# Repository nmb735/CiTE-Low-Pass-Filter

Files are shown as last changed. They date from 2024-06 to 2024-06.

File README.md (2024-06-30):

# 🎚️ CiTE: Fourth Order Low Pass Filter

Full implementation of a fourth-order low-pass filter. The circuit design is based on the use of two cascaded second-order Sallen-Key configurations. Presented as the final project for CiTE (*Circuits i Tecnologies Electròniques*), part of the third course of the Electronic Engineering degree (BSc).

## 👨‍💻 Developers

- Adrià Arús - @Addruss
- Nedal Benelmekki - @nmb735
- Marc Serra - @Marcits

## 📋 Context and Introduction

- This project involves the full implementation of a fourth-order low-pass filter. The circuit design is based on the use of two cascaded second-order Sallen-Key configurations. It was presented as the final project for CiTE (*Circuits i Tecnologies Electròniques*), part of the third course of the Electronic Engineering degree (BSc).

- The project encompassed the entire process, including circuit and PCB design, manufacturing, soldering, and testing.

## 📂 Content

This repository contains the full project in different directories:

1. **`EAGLE Project`**: Full PCB project (`EAGLE` software, from Autodesk), including Layout, Schematic, Gerber Files, BOM, and other related files.
2. **`Documentation`**: Project documentation and presentation poster.

## 📝 License

This project is licensed under the MIT License. See the LICENSE file for more details.

## ⚠️ Disclaimer

This project is provided for educational purposes only. The authors are not responsible for any use of this project in any form of academic dishonesty or plagiarism. Please adhere to your institution's academic integrity policies when using or referencing this project.

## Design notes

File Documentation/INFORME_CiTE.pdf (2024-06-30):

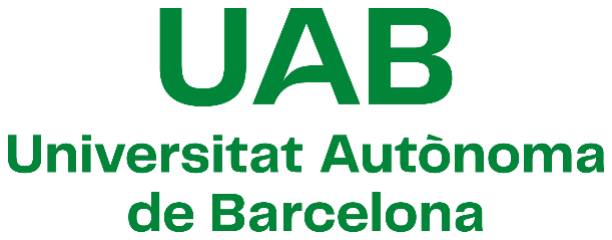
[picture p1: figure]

# DISSENY I FABRICACIÓ D’UN FILTRE EN PCB

ADRIÀ ARÚS SETÓ - 1632367
NEDAL MARTÍNEZ BENELMEKKI - 1632368 MARC SERRA ASENSIO - 1632823

Adrià Arús Setó | Nedal Martínez Benelmekki | Marc Serra Asensio
DISSENY I FABRICACIÓ D’UN FILTRE EN PCB

## Contingut

## Objectiu

Durant les pràctiques, s’havia de dissenyar un filtre passa-baixos (aproximació Butterworth) d’ordre quatre, implementat amb dues configuracions Sallen-Key de segon ordre en cascada.

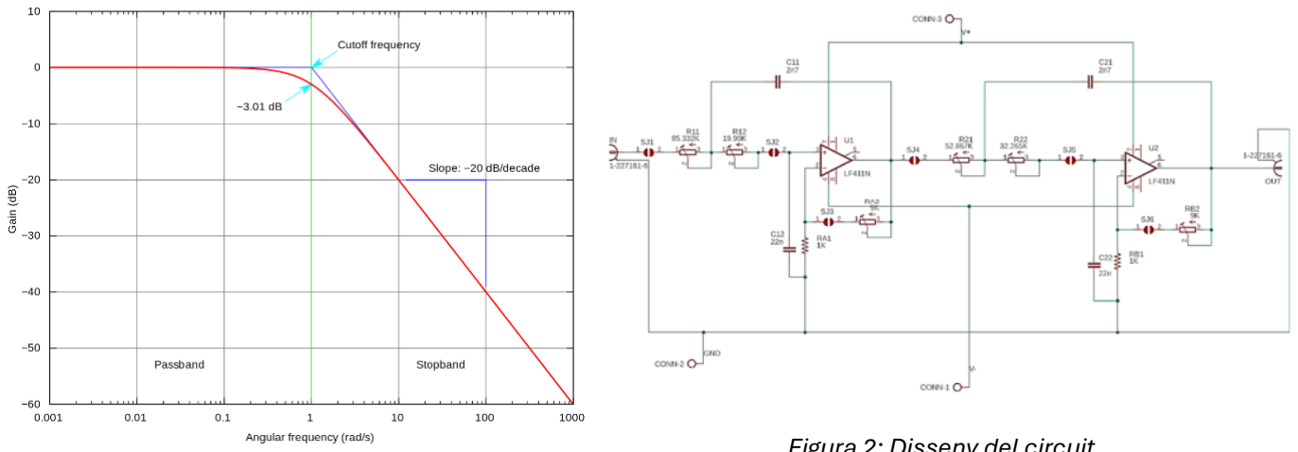
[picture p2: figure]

El filtre tindrà una banda de pas amb un guany de 40 dB (100 en lineal) amb una freqüència de tall de 500 Hz (freqüència on el guany cau 3 dB).

A la primera sessió de pràctiques es va dissenyar el circuit que implementa el filtre, seleccionant els components adequats i amb els valors corresponents. A continuació, a la segona pràctica, es varen descobrir els processos de fabricació d'aquest tipus de plaques. Seguint a la tercera pràctica, on se soldaren els components a la placa, construint el filtre desitjat. Finalment, a la quarta pràctica, es va dur a terme el test del circuit final muntat a la PCB.

Figura 1: Filtre patró

Figura 2: Disseny del circuit.

## Disseny de la PCB

La primera etapa de tot el procés consistia en dissenyar la PCB. Per a aquesta fase de disseny, calia familiaritzar-se amb softwares de tipus ECAD (Electronic Computer Assisted Design). Tot i que hi ha moltes eines diferents, com ara Altium Designer (estàndard de la indústria), CircuitMaker, o KiCad (entre moltes altres), s’ha realitzat tot el procés de disseny mitjançant Eagle, una eina produïda per Autodesk, la prestigiosa empresa d’eines CAD.

En el cas concret de la pràctica, es requerien diverses etapes, o capes, per a realitzar el circuit. En primer lloc, s’havia de crear una llibreria per poder utilitzar un component que no existia en la llibreria per defecte d’Eagle. Un cop creada la llibreria, es requeria desenvolupar l’esquemàtic (schematic), el layout de la placa i els arxius de fabricació. Tanmateix, tot i que no es demanava, per continuar amb les millors pràctiques del disseny electrònic, també s’afegirà una llista de materials (Bill of Materials).

A continuació, es detalla cada un d’aquests subapartats.

### Desenvolupament d’una llibreria

Com bé s’ha esmentat anteriorment, el disseny del filtre proposat s’implementa amb un component que no existeix a les llibreries estàndard del programari Eagle. Així doncs, es procedeix a crear una llibreria pròpia amb un únic component: el potenciòmetre TSM4 de Vishay.

A l’hora de definir una llibreria, hi ha quatre camps que es poden emplenar: dispositius, footprints, paquets 3D i símbols. Com que no es visualitzarà el render de la placa en 3D (ja que això se surt de l’abast de la pràctica) i només s’hi afegeix un dispositiu, s’hauran d’emplenar tres camps. En primer lloc, es tracta el símbol. Des del punt de vista de component per a un esquemàtic, el TSM4 continuarà sent un potenciòmetre (amb tres terminals) i, per tant, es pot reutilitzar un símbol més general d’un potenciòmetre. Específicament, s’ha utilitzat el símbol corresponent a POT-EU.

Un cop definit el símbol, cal crear el seu footprint. El footprint del
component descriu com és físicament i té importància a l’hora de
dissenyar el layout de la PCB. Mitjançant el footprint es defineixen característiques fonamentals del component, com ara la naturalesa de la seva tecnologia (SMD – Surface Mount Device, o THD – Through Hole Device) i les seves dimensions. Al datasheet del component es troben les dimensions corresponents, i s’ha aconseguit implementar el footprint i el corresponent silkscreen (per poder localitzar correctament el component en la placa física). A continuació, s’adjunta una figura amb el resultat final.

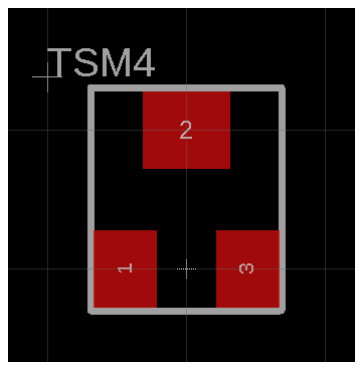
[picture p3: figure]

Figura 3: Implementació del footprint del TSM4

Un cop obtingut el footprint i el símbol del component, el següent i últim pas és el Device. El dispositiu (Device) és la integració del símbol amb el footprint per acabar de caracteritzar el component mitjançant la relació entre les connexions del símbol elèctric i les parts reals i/o físiques, i la petjada del component. Un cop finalitzat aquest procés, es pot desar la llibreria al directori on es troben les altres llibreries d’Eagle. D’aquesta manera, el component desitjat ja pot ser utilitzar en els dissenys a partir de la importació de la llibreria.

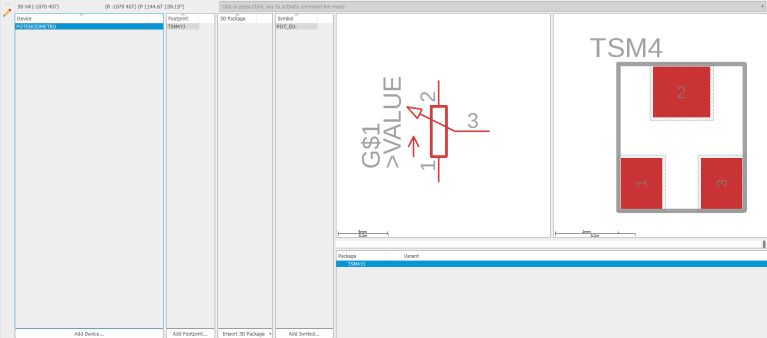
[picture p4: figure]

Figura 4: Llibreria finalitzada. Símbol, footprint i device acabats.

### Schematic (Esquemàtic)

La generació del schematic és una etapa relativament senzilla. Gràcies a la realització de la “Pràctica 0”, ja es disposa del disseny del filtre amb el circuit en format PDF, es proporciona la llista de components, i amb la implementació de la llibreria es té accés a tots els components. D’aquesta manera, només cal implementar el circuit, de manera molt similar a com es fa en simuladors SPICE.

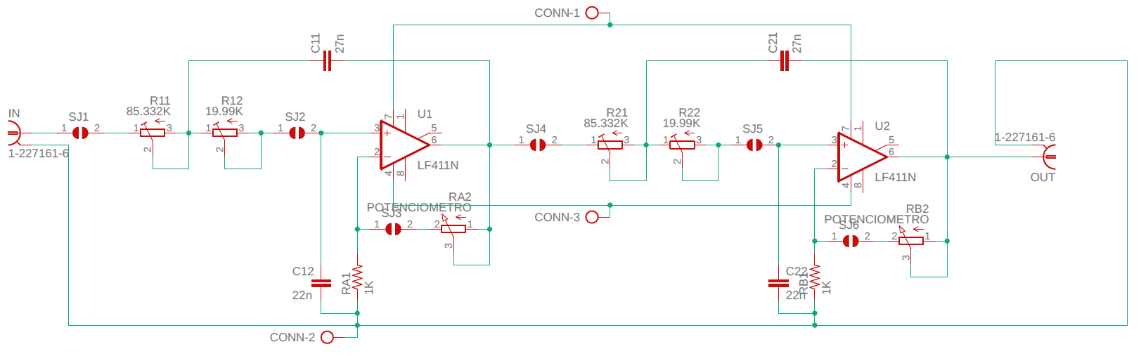
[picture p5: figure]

Figura 5: Schematic realitzat.
Cal recalcar, però, que generalment els schematics en eines de disseny de PCBs no es realitzen d’aquesta manera. En aquest cas particular, a causa de la simplicitat del circuit i la seva repetitivitat (dues configuracions Sallen-Key de segon ordre en cascada), a més de la familiaritat amb eines SPICE, es permet enfocar el disseny del schematic així. No obstant això, generalment en aquest apartat es troben els diversos mòduls de la PCB, ordenats segons la seva utilitat i no pel seu layout. En aquest cas, es podrien haver separat les dues configuracions Sallen-Key com a dos mòduls separats i indicar la seva connexió per nom (etiquetant el net), però es pot argumentar que això afegiria una capa de complexitat innecessària.

Finalment, es revisa que no hi hagi cap error amb l'Electrical Rule Check (ERC). A causa que components com l’amplificador operacional no s’alineen bé amb la resta, ha calgut solucionar alguns avisos de connexions que “estaven molt a prop, però no es tocaven”. S’han solucionat aquests avisos, però encara queden altres que no s’han pogut resoldre, com la falta de valors de components (marca tots els jumpers i I/O BNC com a warning) i les alimentacions de l’amplificador operacional. El més important, però, és que supera l’ERC sense cap errada. S’adjunta una imatge a continuació.

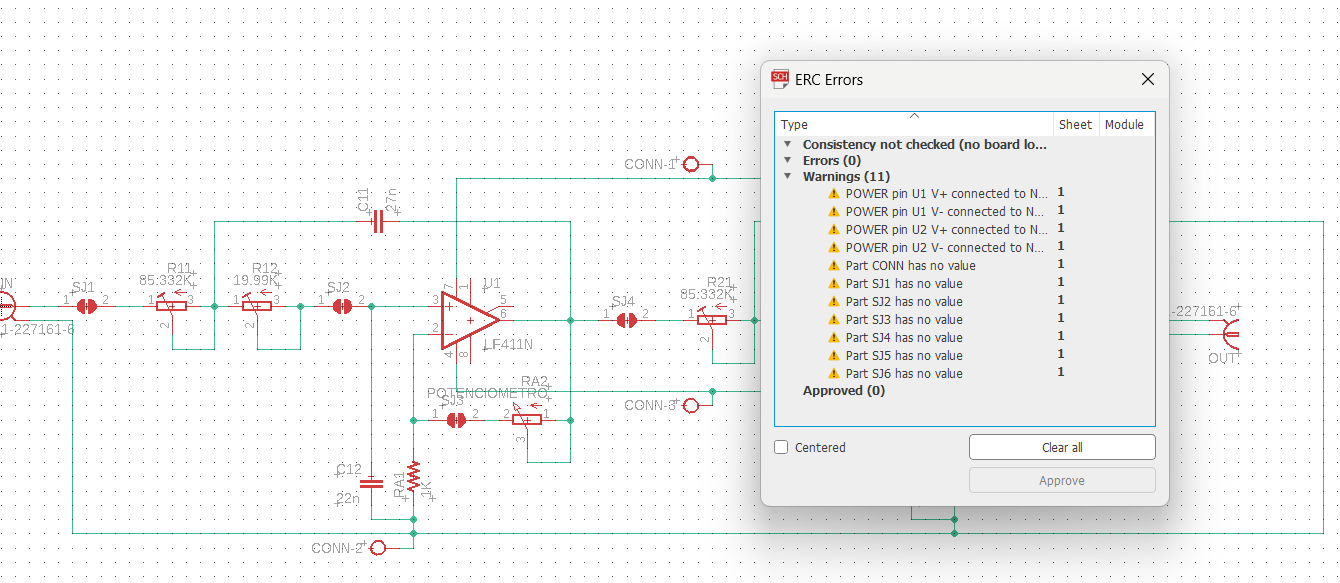
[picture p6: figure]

Figura 6: Schematic sense errades.

### Layout de la PCB

Un cop finalitzat el Schematic, es procedeix a realitzar el Layout. Per l’experiència obtinguda i per la documentació d’Eagle, és convenient mantenir obert tant l’esquemàtic com l’arxiu de layout, ja que d’aquesta manera se sincronitzen els canvis automàticament.

Inicialment, s’havia de definir la mida de la PCB. A la capa de Dimensions es defineix el polígon equivalent i s’adjunten les mesures. Posteriorment, es defineixen les regles DRC, es realitzen els forats de fixació, es col·loquen els components, es realitzen les vies (a la capa bottom) i s’afegeix el pla de massa (a la capa top). El resultat final és el següent:

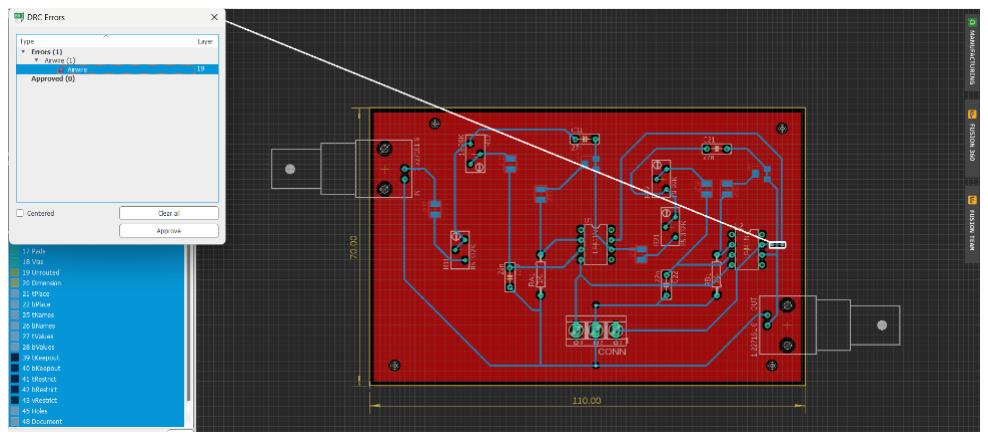
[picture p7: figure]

Figura 7: Resultat final de PCB.

Com bé es pot observar, hi ha una errada de circuit obert. Aquesta no es pot resoldre, ja que per la naturalesa del nostre circuit, és impossible trobar un camí del circuit que no causi un encreuament. De fet, si es modela el circuit com un graf, aquest no compliria el principi d’Euler, confirmant així la hipòtesi. A conseqüència s’afegeixen dues vies, per, de manera igual a la que es va fer experimentalment al laboratori, es pugui utilitzar un jumper wire (pont) per realitzar la connexió.

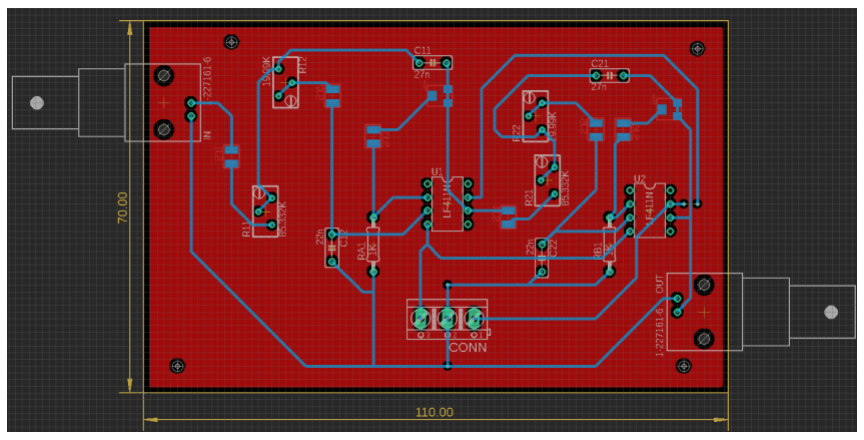
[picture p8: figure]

Figura 8: Layout de la PCB.
Així doncs, s’ha realitzat el layout de la PCB. Per comprovar que està tot correcte (temes de silkscreen, o forats, entre d’altres), s’utilitza l’eina “Manufacturing” d’Eagle, que permet veure un render en dues dimensions de la placa:

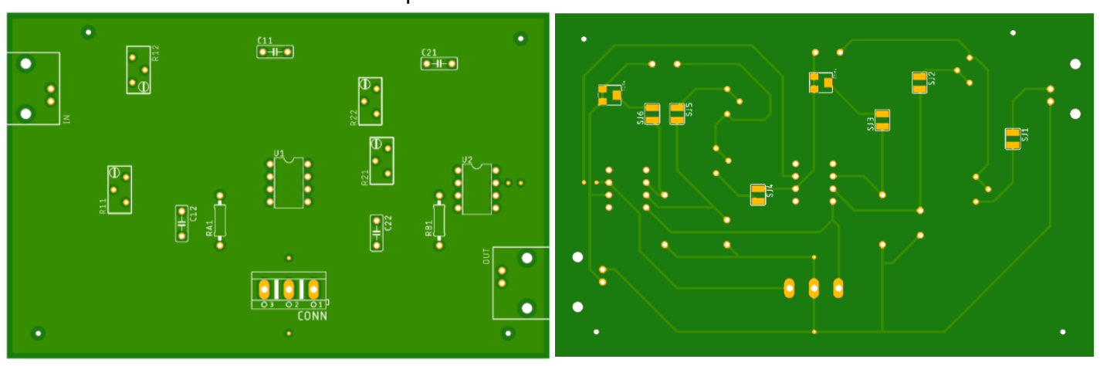
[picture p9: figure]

Figura 9: Render de la PCB en dues dimensions (Esquerra: capa top, Dreta: capa bottom)

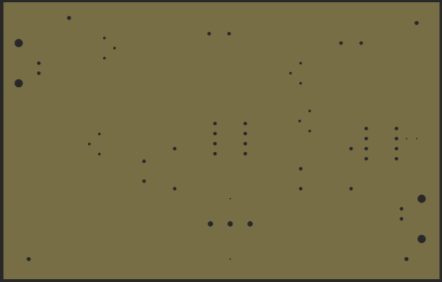
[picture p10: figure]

Figura 10: Render dels forats (drills) de la PCB.

### Arxius de fabricació i Bill of Materials

Des del Schematic, seleccionem “File”, després “Export” i finalment “BOM”. D’aquesta manera, es pot exportar un llistat del BOM (Bill of Materials). S’ha afegit aquest arxiu a la carpeta del projecte, en format CSV (BOM.csv).

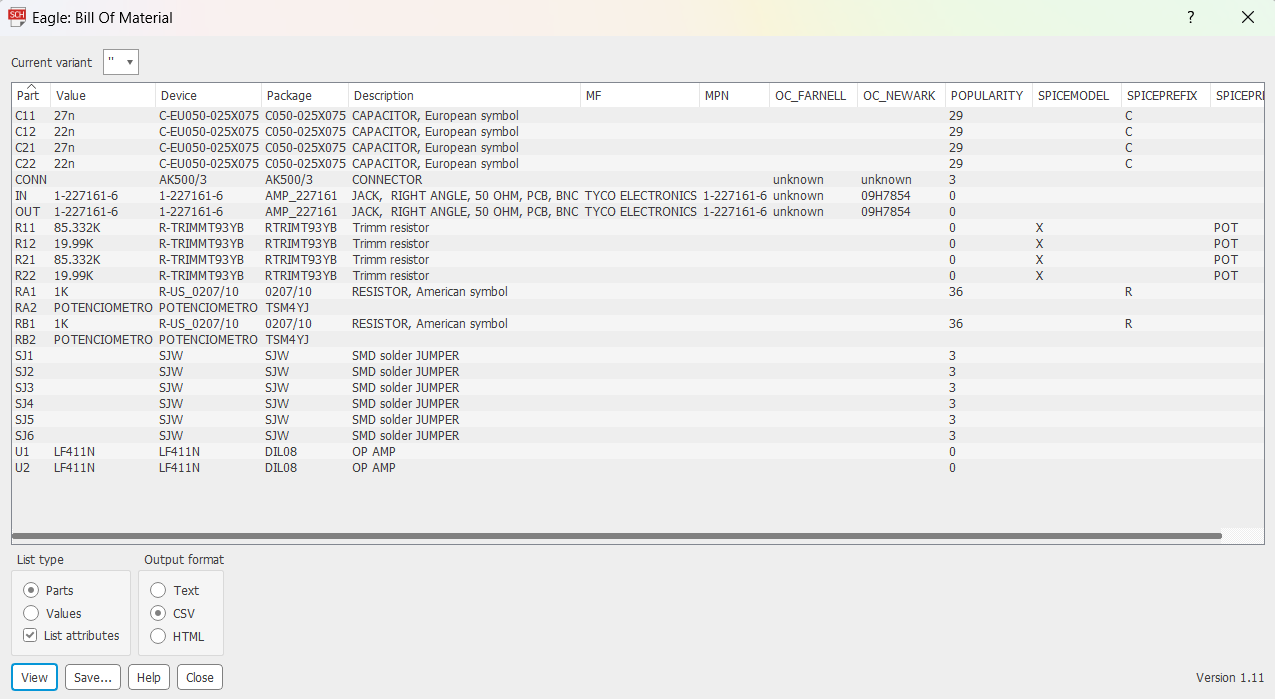
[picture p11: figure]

Figura 11: Generació del BOM.
Finalment, des de l’arxiu del layout, se selecciona l’opció de generar els fitxers Gerber (Generate CAM data). S’emmagatzemen aquests arxius en una carpeta ZIP al directori del projecte (Gerber_Files.zip).

## Fabricació de la placa

En una de les sessions de les pràctiques es van explicar tres processos de fabricació d’una placa PCB. Dos d’aquests processos eren de tipus subtractiu i l’altre de tipus additiu. Els processos subtractius consisteixen en el fet que el material conductor amb el que es fan les pistes es troben inicialment a la placa i es treu d’allà on no es vol. Per contra, els processos additius consisteixen a afegir el material conductor a un substrat que inicialment no el té.

Veiem ara en més detall cada un dels processos.

### Fotolitografia

Es tracta d'un dels dos processos subtractius i consisteix a remoure el coure a partir d'atacs químics en aquelles zones desprotegides d'una resina sensible a la llum. Els passos són els següents:
Primerament, es fa una rentada del coure tot per evitar impureses com l'òxid de coure a causa de l'exposició amb l'aire. Seguidament, es fa la sensibilització que consisteix a dipositar una resina fotosensible. Aquests dos primers passos no es van veure, ja que la placa PCB ja venia amb la resina fotosensible protegint la superfície del coure.
El procés continua amb la definició de la màscara a partir d'una impressora en un material transparent. En el cas de les pràctiques, les parts que tapava la màscara eren les pistes deixant al descobert la resina fotosensible allà on no volem coure. Idealment, els coeficients d'expansió tèrmica del material transparent és igual al de la placa. En cas contrari, es podria perdre definició.
Seguidament, s'exposa la resina fotosensible a llum ultraviolada (la més energètica per accelerar el procés) en una insoladora per debilitar les parts desprotegides de la màscara. Cal tenir en compte que hi ha casos on succeeix el contrari, és a dir, que és la part que no ha rebut llum ultraviolada la debilitada, però en les pràctiques es va veure el primer cas.
Després es fa un revelatge retirant la resina debilitada amb sosa càustica (molt
diluïda) exposant així el coure que es vol remoure de la placa. A continuació es fa l'atac químic en el qual es treu el coure amb clorur fèrric en aquelles parts on no hi ha resina.

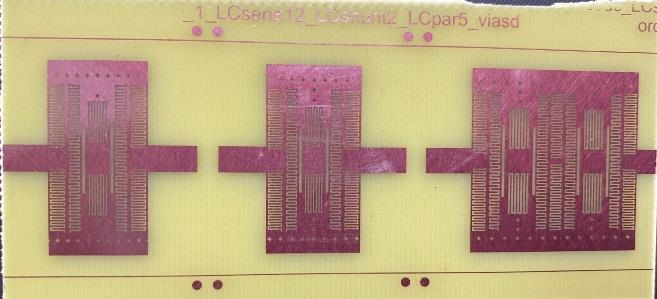
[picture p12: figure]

Figura 12: Exemple de fotolitografia després del revelatge
Finalment es fa un despreniment de la resina que en s’ha servit per protegir el coure de les pistes.

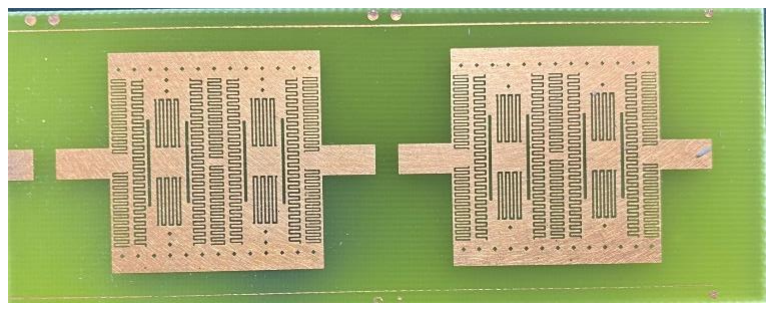
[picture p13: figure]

Figura 13: Resultat final

### Fresat

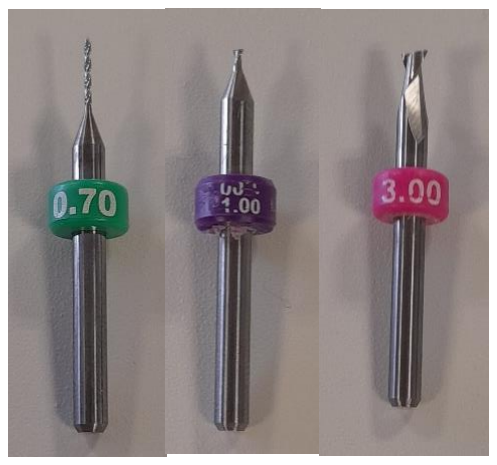
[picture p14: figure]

Aquesta és l’altra tècnica subtractiva. En aquest cas es remou el coure amb una màquina que té una peça giratòria anomenada fresa. El procediment que segueix la màquina consisteix en els passos descrits a continuació.

Primer la màquina s’alinea de manera automàtica i es fan els forats. Seguidament remou el coure amb les freses. Aquestes són de carbur tungstè i es van canviant de diàmetre segons la necessitat (poden anar des de 0.2 mm fins a 3 mm).

Finalment es talla per obtenir la peça.

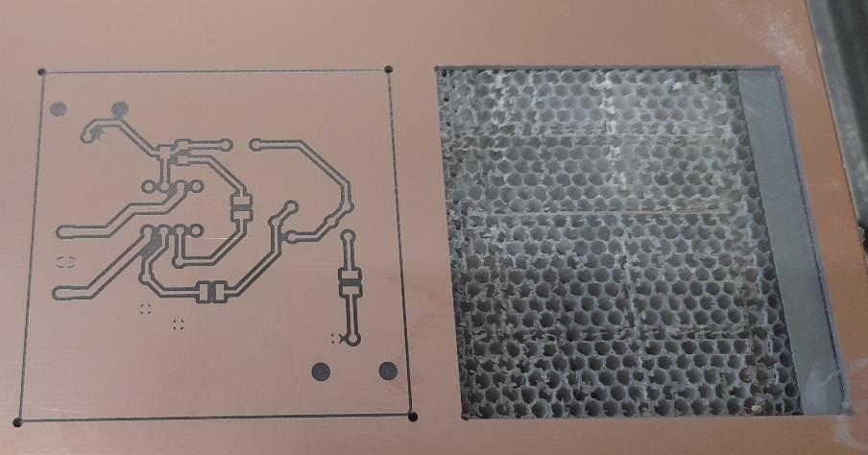
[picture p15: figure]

Figura 15: Lamina abans i després del tall
Aquest procediment té com a contrapartida que és notablement més car, ja que les freses són cares i es desgasten amb l’ús.

### Impressió amb tinta conductora

Aquesta darrera tècnica és l'additiva, també coneguda com a "injecció de tinta". Com bé indica el seu nom, es basa en una màquina (amb un cost d'aproximadament 5.000 €) que imprimeix les

Figura 14: Freses de diferents mides pistes directament sobre la placa mitjançant uns cartutxos de tinta, que costen uns 100 € cadascun.

El procés d'ús és força senzill en comparació amb les dues tècniques anteriors. La màquina esmentada, mitjançant un èmbol i l'aplicació de pressió sobre aquest, dissipa un material (generalment plata o algun altre material amb partícules de plata). Aquesta impressió es pot realitzar des d'una plantilla o a mà alçada, amb la placa en blanc. Així, indicant al programari associat a la màquina quin tipus de tinta es té, i seguint les instruccions proporcionades (és un procés molt guiat), es pot començar a imprimir el circuit. Cal tenir en compte que la placa sobre la qual s'imprimeix ha de ser plana i uniforme.

Un cop realitzada tota aquesta fase de preparació, es pot procedir a la impressió del circuit. Inicialment, s'ha de muntar la punta de calibració, on es calibrarà l'alçada, es farà una calibració en moviment, i es marcaran els límits del circuit. Un cop calibrat, es començarà a pintar amb un patró de "tocs" per acabar la calibració. La finalització d'aquests "tocs" marca la fi del procés de calibració. El programari ho indicarà i donarà la instrucció de començar la impressió.

Girant l'èmbol s'aconsegueix afegir pressió fins que surti la tinta. Quan això succeeix, netegem la punta i la col·loquem a la màquina. La màquina imprimirà unes línies de calibració. Si està tot correcte, es continua seguint les instruccions del programari. Si no, es pot esborrar amb alcohol i paper, ja que el material encara no s'ha solidificat.

Finalment, es procedeix a imprimir el circuit. Cal
anar amb compte perquè s'han de curar les pistes
per acabar de solidificar-les. Amb el circuit resultant, es poden soldar components manualment, tenint en compte les limitacions de material i temperatura. No obstant això, també existeix l'opció de soldar amb la mateixa màquina, canviant el material de la tinta.

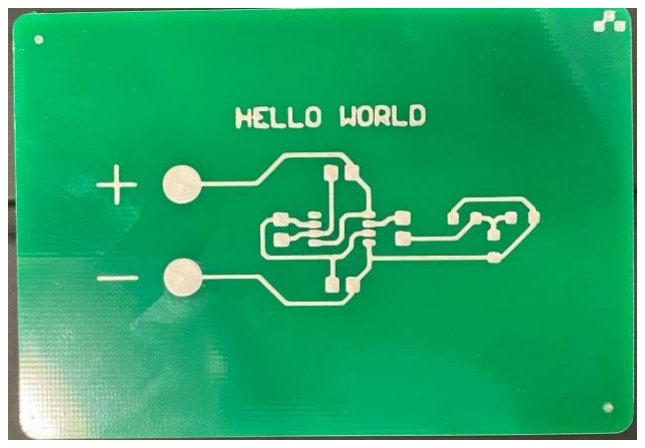
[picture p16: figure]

Figura 16: Resultat de la tècnica additiva

## Muntatge dels components

En el cas de les pràctiques, es van fer soldadures a mà dels diferents components sobre la placa PCB. A més dels components necessaris, es van utilitzar un soldador amb una esponja mullada, estany i una malla metàl·lica.

Abans de començar, calia escalfar el soldador a la temperatura correcta, la qual cosa es comprovava amb una mica d’estany. El procés de soldar consistia a escalfar el metall de la placa i del component, i un cop calent, afegir l’estany perquè la soldadura quedés ben mullada i sense excessos de material.

Aquest grup va tenir problemes inicials per entendre bé el funcionament, però finalment es van realitzar totes les soldadures satisfactòriament. Es va demanar feedback al professorat, i es van rebre comentaris positius quant a la qualitat de les soldadures. A continuació es mostren fotografies dels resultats.

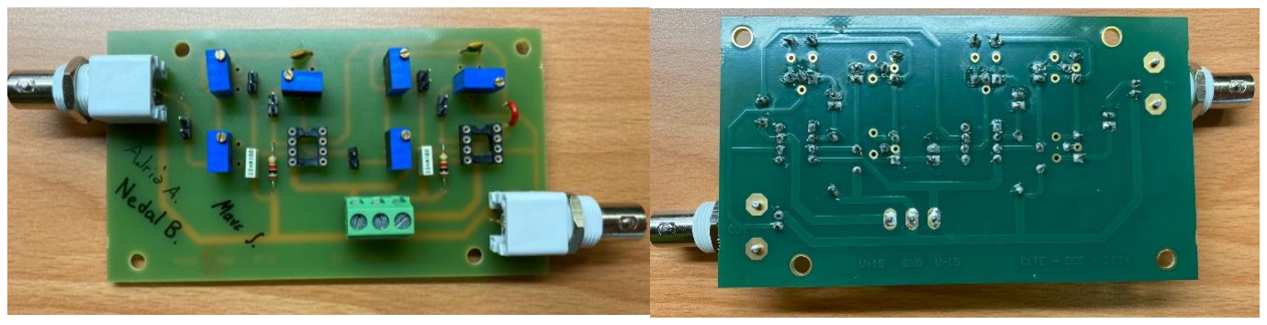
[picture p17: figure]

Figura 17: Resultats del muntatge.

## Test del circuit

Una vegada implementada la placa, s’han calibrat els components amb els valors nominals. Per testejar el funcionament del filtre, es fa un escombrat de freqüències veient el resultat. S’ha generat un diagrama de Bode per a poder comprovar que el nostre sistema funciona correctament:

f [Hz] | Vin [V] | Vout [V] | G | G [dB] | Atenuació [dB]
1,00E+00 | 1,00E-01 | 1,24E+01 | 124 | 41,8684337 | 0
1,00E+01 | 1,00E-01 | 1,24E+01 | 124 | 41,8684337 | 0
1,00E+02 | 1,00E-01 | 1,24E+01 | 124 | 41,8684337 | 0
1,25E+02 | 1,00E-01 | 1,17E+01 | 1,17E+02 | 41,34885686 | 0,519576848
1,50E+02 | 1,00E-01 | 1,09E+01 | 1,09E+02 | 40,73257791 | 1,135855796
1,75E+02 | 1,00E-01 | 9,76E+00 | 9,76E+01 | 39,78899635 | 2,07943735
2,00E+02 | 1,00E-01 | 8,68E+00 | 8,68E+01 | 38,7703945 | 3,0980392
2,25E+02 | 1,00E-01 | 7,60E+00 | 7,60E+01 | 37,61627185 | 4,252161858
2,50E+02 | 1,00E-01 | 6,60E+00 | 6,60E+01 | 36,39087871 | 5,477554992
2,75E+02 | 1,00E-01 | 5,68E+00 | 5,68E+01 | 35,08696671 | 6,781466989
3,00E+02 | 1,00E-01 | 4,88E+00 | 48,8 | 33,76839644 | 8,100037263
3,50E+02 | 1,00E-01 | 3,48E+00 | 3,48E+01 | 30,83158488 | 11,03684882
4,00E+02 | 1,00E-01 | 2,48E+00 | 2,48E+01 | 27,88903362 | 13,97940009
4,50E+02 | 1,00E-01 | 1,80E+00 | 1,80E+01 | 25,1054501 | 16,7629836
5,00E+02 | 1,00E-01 | 1,28E+00 | 1,28E+01 | 22,14419939 | 19,72423431
5,50E+02 | 1,00E-01 | 9,38E-01 | 9,38 | 19,44405677 | 22,42437694
6,00E+02 | 1,00E-01 | 7,14E-01 | 7,14 | 17,07396424 | 24,79446947
7,00E+02 | 1,00E-01 | 4,24E-01 | 4,24 | 12,54731713 | 29,32111657
8,00E+02 | 1,00E-01 | 2,60E-01 | 2,6 | 8,299466959 | 33,56896674
9,00E+02 | 1,00E-01 | 2,00E-01 | 2 | 6,020599913 | 35,84783379
1,00E+03 | 1,00E-01 | 1,82E-01 | 1,82 | 5,20142776 | 36,66700594
2,00E+03 | 1,00E-01 | 1,40E-01 | 1,4 | 2,922560714 | 38,94587299
5,00E+03 | 1,00E-01 | 9,60E-02 | 9,60E-01 | -0,354575339 | 42,22300904

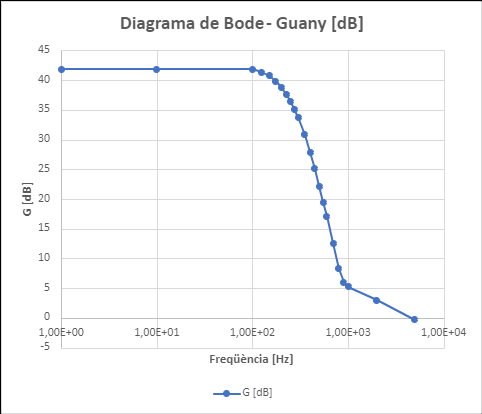
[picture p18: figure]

Figura 18: Diagrama de Bode utilitzant els valors nominals.

S'observa la forma d'un filtre Butterworth passa-baixos, amb un guany d'uns 41 dB (124 en lineal) a la banda de pas i una freqüència de tall de al voltant de 200 Hz. A la banda atenuant es veu un pendent d'uns 80 dB per dècada, conseqüència de l'ordre 4 del filtre.
Es pot comparar el resultat d'amplificar un senyal en la banda de pas (100 Hz) amb el de la banda atenuant (400 Hz) per a una entrada d'amplitud 50 mV:

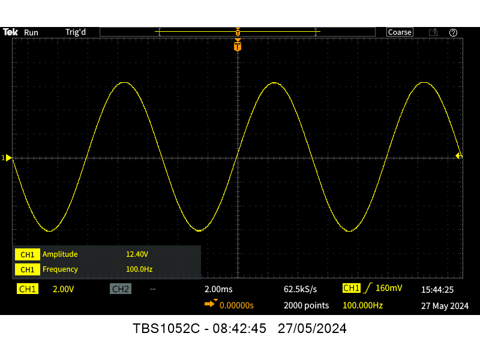
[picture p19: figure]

Figura 19: Guany a la banda passant.

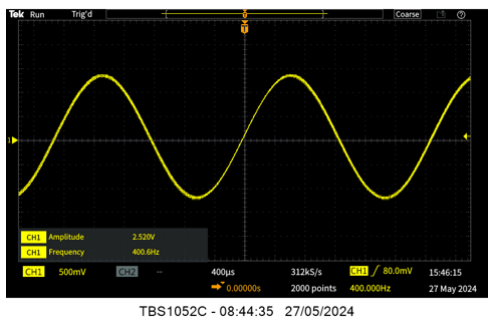
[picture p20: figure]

Figura 20: Guany/Atenuació a la banda d'atenuació.

Ajustant els valors als del disseny s’obté el següent diagrama de Bode:

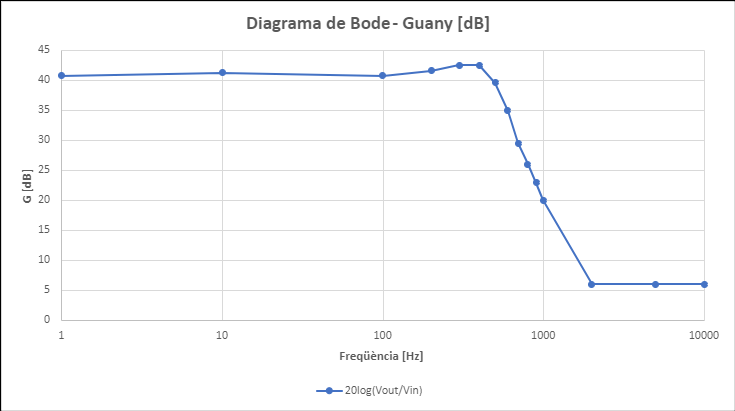
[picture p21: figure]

Figura 21: Diagrama de Bode amb els valors ajustats.

Com es pot observar, a causa de no idealitats tenim un factor de qualitat més elevat del desitjat.

En conclusió, el nostre sistema implementa un filtre Butterworth passa-baix totalment funcional.

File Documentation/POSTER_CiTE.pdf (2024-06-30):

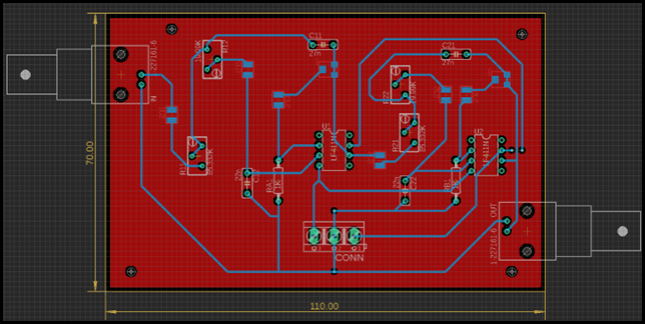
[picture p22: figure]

Adrià Arús Setó (1632367)

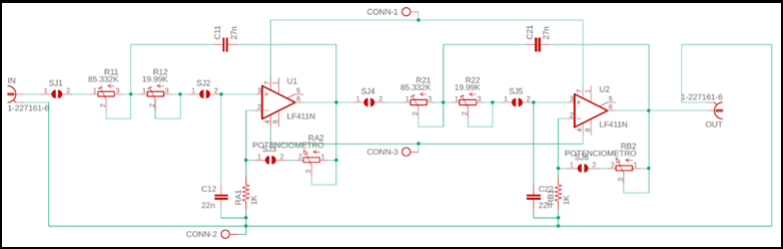
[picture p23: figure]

Nedal Martínez Benelmekki (1632368) Marc Serra Asensio (1632823)

### Autors

Universitat Autònoma de Barcelona (UAB) Circuits i Tecnologies Electróniques

El disseny de la PCB s

’ha realitzat mitjançant el programari Eagle. S’han realitzat les següents etapes:

Desenvolupament d’una llibreria En el disseny proposat, existia un component no present en les llibreries d’Eagle. Consequentment, s

’ha implementat una llibreria (símbol, footprint, i device) per poder utilitzar el component (TSM4 de Vishay).

Schematic (Esquemàtic)
Realització d’

un dels arxius més importants d’

un projecte de disseny de PCB. S’ha comprovat que no hi ha cap errada ERC (Electrical Rule Check).

Layout de la PCB
Realització del layout de la placa, tenint en compte les dimensions físiques (de components i placa) i les regles de disseny.

Arxius de fabricació i Bill of Materials Generació dels arxius de fabricació (Gerber files) a partir del layout (emmagatzemats en un ZIP), i generació del BOM (Bill of Materials) a partir del schematic. Mitjançant aquests dos, es pot iniciar la etapa de producció i muntatge.

Implementació del footprint

Schematic del circuit

Layout de la PCB i renders en dues dimensions de la capa top (centre) i la capa bottom (esquerra).

Resultats del muntatge

Dissenyar un filtre passa-baixos de les següents característiques:
Aproximació Butterworth
Ordre quatre
Implementat amb dues configuracions Sallen-Key de segon ordre en cascada
Guany de 40dB a la banda passant Freqüència de tall de 500 Hz

Implementar el filtre en una PCB, realitzant: Procés de disseny de la placa
Exploració de les tècniques de fabricació Realització del muntatge de la PCB
Comprovació del funcionament (Test del circuit)

# 01 Objectiu

# 02 Disseny de la PCB

Es van realitzar soldadures a mà dels diferents components sobre la placa PCB. A més dels components necessaris, es va utilitzar un soldador amb una esponja mullada, estany i una malla metàl·lica.

Abans de començar, calia escalfar el soldador a la temperatura correcta, la qual cosa es comprovava amb una mica d’

estany. El procés
de soldar consistia en escalfar el metall de la placa i del component, i un cop calent, afegir l’

estany perquè la soldadura quedés ben mullada i sense excessos de material.

# 04 Muntatge dels components

Un cop implementada la placa, es calibren els components amb els valors nominals. Per testejar el funcionament del filtre, es fa un escombrat de freqüències i es realitza el Diagrama de Bode:
Es pot obervar que, efectivament, es tracta d’

un filtre
passa baixos d’

aproximació Butterworth.
El guany a la banda passant coincideix amb el disseny inicial.
La freqüència de tall, però, és més baixa del que s ’ha
esperat (de 500 Hz a 200Hz, aproximadament).

Per tractar de corregir la freqüència de tall, es procedeixen a calibrar i ajustar els valors resistius dels potenciòmetres. Finalment, s

’ha aconseguit el resultat següent:

# 05 Test del circuit

# Disseny i fabricació d’un filtre en

# PCB

## Projecte final de la part de

pràctiques de laboratori.

Es van explorar i explicar els següents tres processos de fabricació d’
una placa PCB:

# 03 Fabricació de la placa

Fotolitografia: procés subtractiu que consisteix en remoure el coure a partir d’
atacs químics en
aquelles zones desprotegides d’
una resina
sensible a la llum.
Fresat: procés subtractiu que consisteix en remoure el coure amb una màquina que té una peça giratòria anomenada fresa.
Impressió amb tinta conductora: tècnica additiva que es basa en una màquina que imprimeix les pistes directament sobre la placa.

Diagrama de Bode amb valors nominals

Diagrama de Bode amb valors calibrats

Es pot afirmar que:
El guany a la banda passant coincideix amb el disseny inicial.
La freqüència de tall és de 500 Hz, aproximadament.
A causa de no idealitats tenim un factor de qualitat més elevat del desitjat

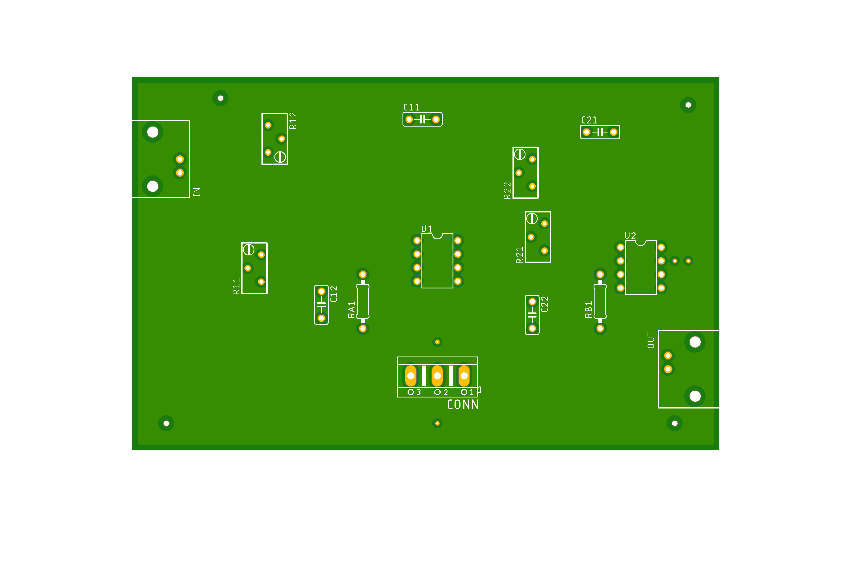
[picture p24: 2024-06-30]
EAGLE-Project/PCB-Layout-Renders/pcb_top.png

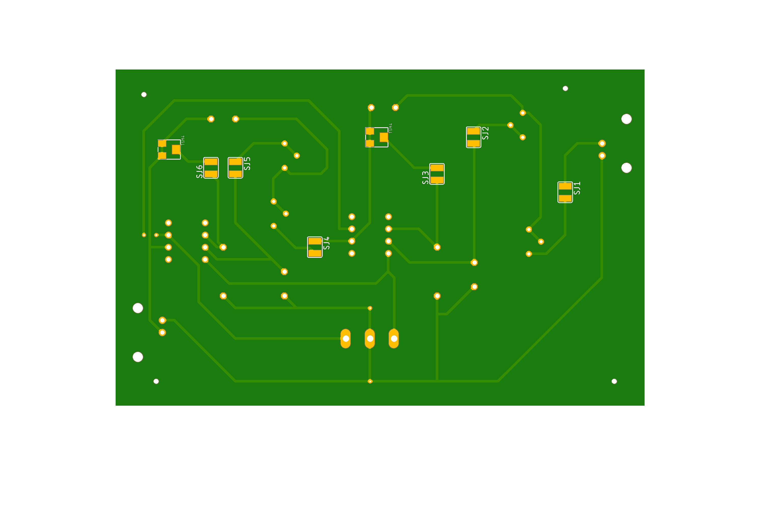
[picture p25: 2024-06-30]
EAGLE-Project/PCB-Layout-Renders/pcb_bottom.png

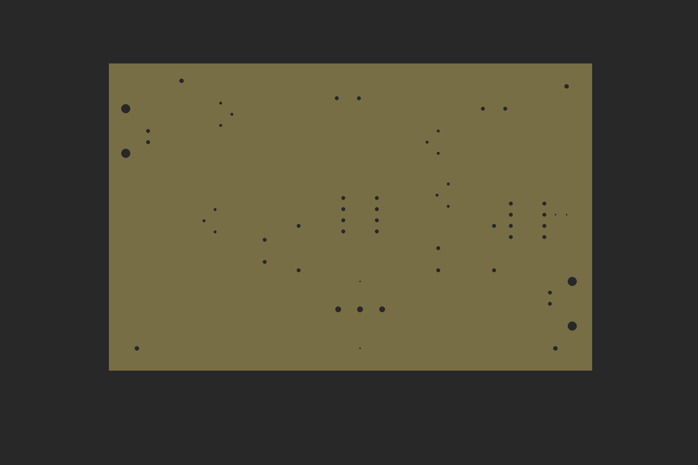
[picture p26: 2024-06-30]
EAGLE-Project/PCB-Layout-Renders/pcb_drills.png

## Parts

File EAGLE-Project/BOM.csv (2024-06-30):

Part | Value | Device | Package | Description | MF | MPN | OC_FARNELL | OC_NEWARK | POPULARITY | SPICEMODEL | SPICEPREFIX | SPICEPREFIXL
C11 | 27n | C-EU050-025X075 | C050-025X075 | CAPACITOR, European symbol |  |  |  |  | 29 |  | C
C12 | 22n | C-EU050-025X075 | C050-025X075 | CAPACITOR, European symbol |  |  |  |  | 29 |  | C
C21 | 27n | C-EU050-025X075 | C050-025X075 | CAPACITOR, European symbol |  |  |  |  | 29 |  | C
C22 | 22n | C-EU050-025X075 | C050-025X075 | CAPACITOR, European symbol |  |  |  |  | 29 |  | C
CONN |  | AK500/3 | AK500/3 | CONNECTOR |  |  | unknown | unknown | 3
IN | 1-227161-6 | 1-227161-6 | AMP_227161 | JACK, RIGHT ANGLE, 50 OHM, PCB, BNC | TYCO ELECTRONICS | 1-227161-6 | unknown | 09H7854 | 0
OUT | 1-227161-6 | 1-227161-6 | AMP_227161 | JACK, RIGHT ANGLE, 50 OHM, PCB, BNC | TYCO ELECTRONICS | 1-227161-6 | unknown | 09H7854 | 0
R11 | 85.332K | R-TRIMMT93YB | RTRIMT93YB | Trimm resistor |  |  |  |  | 0 | X |  | POT
R12 | 19.99K | R-TRIMMT93YB | RTRIMT93YB | Trimm resistor |  |  |  |  | 0 | X |  | POT
R21 | 85.332K | R-TRIMMT93YB | RTRIMT93YB | Trimm resistor |  |  |  |  | 0 | X |  | POT
R22 | 19.99K | R-TRIMMT93YB | RTRIMT93YB | Trimm resistor |  |  |  |  | 0 | X |  | POT
RA1 | 1K | R-US_0207/10 | 0207/10 | RESISTOR, American symbol |  |  |  |  | 36 |  | R
RA2 | POTENCIOMETRO | POTENCIOMETRO | TSM4YJ
RB1 | 1K | R-US_0207/10 | 0207/10 | RESISTOR, American symbol |  |  |  |  | 36 |  | R
RB2 | POTENCIOMETRO | POTENCIOMETRO | TSM4YJ
SJ1 |  | SJW | SJW | SMD solder JUMPER |  |  |  |  | 3
SJ2 |  | SJW | SJW | SMD solder JUMPER |  |  |  |  | 3
SJ3 |  | SJW | SJW | SMD solder JUMPER |  |  |  |  | 3
SJ4 |  | SJW | SJW | SMD solder JUMPER |  |  |  |  | 3
SJ5 |  | SJW | SJW | SMD solder JUMPER |  |  |  |  | 3
SJ6 |  | SJW | SJW | SMD solder JUMPER |  |  |  |  | 3
U1 | LF411N | LF411N | DIL08 | OP AMP |  |  |  |  | 0
U2 | LF411N | LF411N | DIL08 | OP AMP |  |  |  |  | 0

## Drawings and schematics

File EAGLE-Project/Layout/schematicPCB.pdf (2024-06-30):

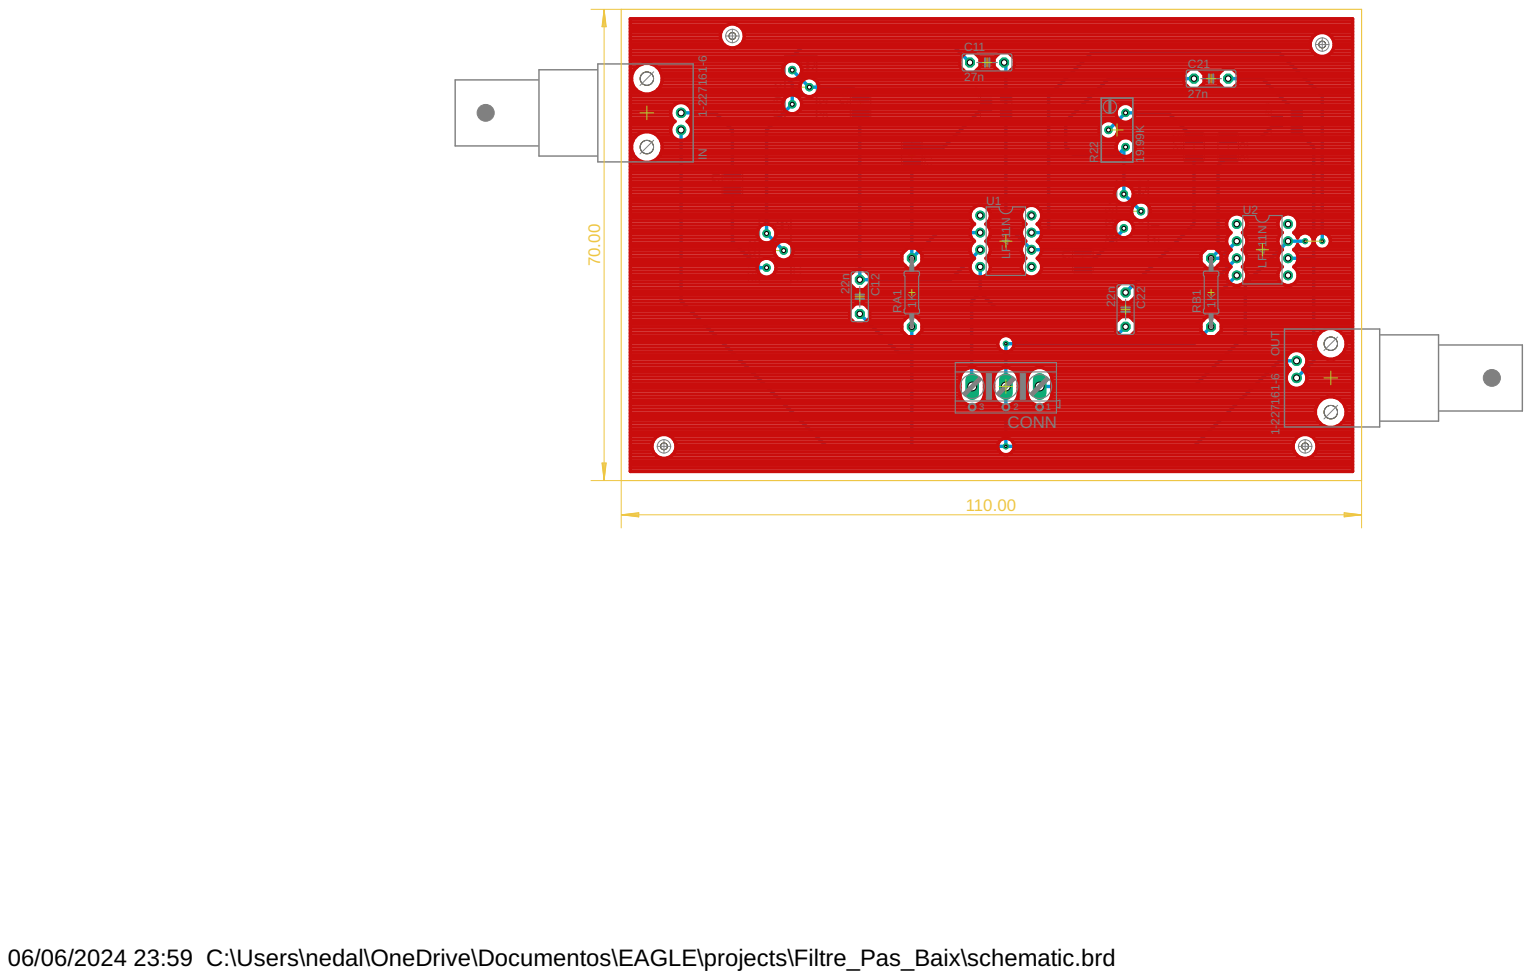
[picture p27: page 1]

06/06/2024 23:59 C:\Users\nedal\OneDrive\Documentos\EAGLE\projects\Filtre_Pas_Baix\schematic.brd

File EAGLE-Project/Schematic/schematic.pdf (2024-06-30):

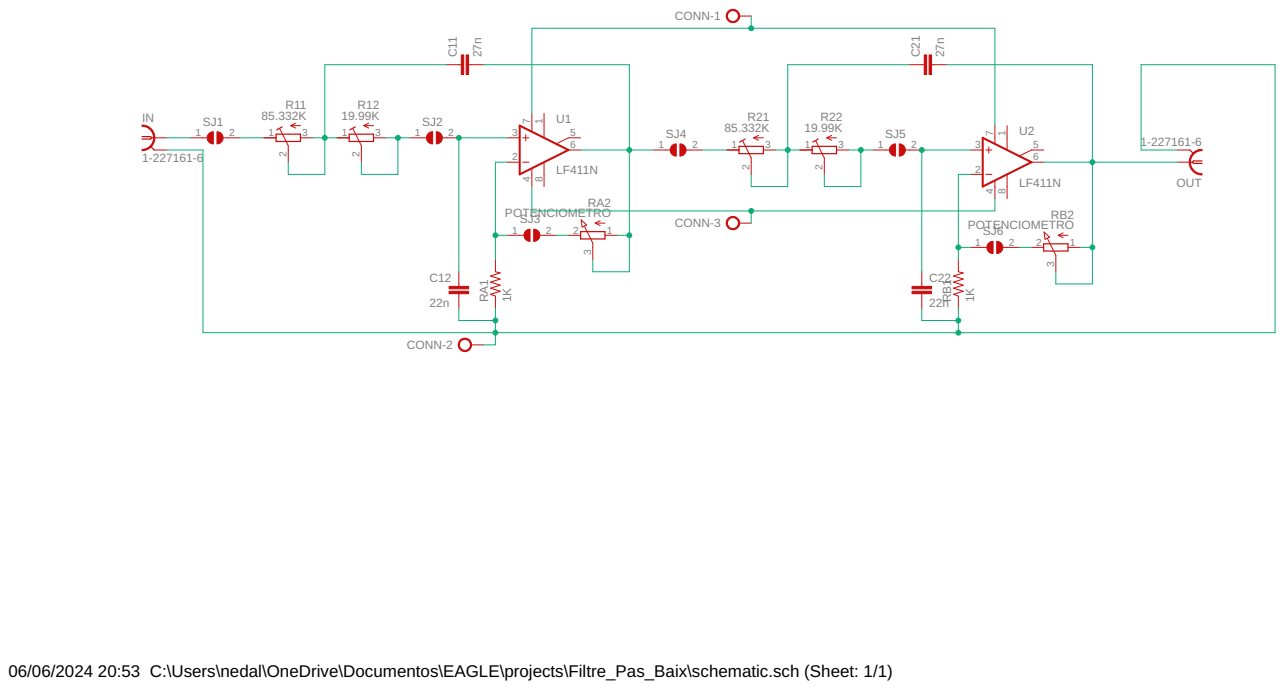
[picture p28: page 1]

06/06/2024 20:53 C:\Users\nedal\OneDrive\Documentos\EAGLE\projects\Filtre_Pas_Baix\schematic.sch (Sheet: 1/1)

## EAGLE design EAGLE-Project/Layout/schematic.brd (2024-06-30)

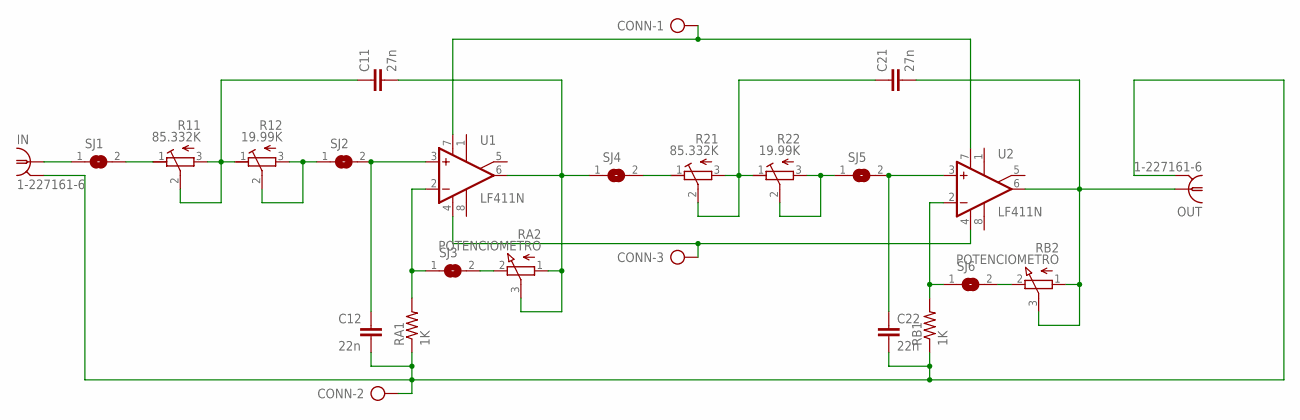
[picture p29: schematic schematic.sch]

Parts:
C11, C21: 27n; C050-025X075
C12, C22: 22n; C050-025X075
CONN: AK500/3
IN: 1-227161-6; AMP_227161
OUT: 1-227161-6; AMP_227161
R11, R21: 85.332K; RTRIMT93YB
R12, R22: 19.99K; RTRIMT93YB
RA1: 1K; 0207/10
RA2: POTENCIOMETRO; TSM4YJ
RB1: 1K; 0207/10
RB2: POTENCIOMETRO; TSM4YJ
SJ1, SJ2, SJ3, SJ4, SJ5, SJ6: SJW
U1, U2: LF411N; DIL08

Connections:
unnamed: IN.1, SJ1.1
unnamed: R11.1 (E), SJ1.2
unnamed: C11.1, R11.2 (S), R11.3 (A), R12.1 (E)
unnamed: R12.2 (S), R12.3 (A), SJ2.1
unnamed: C12.1, SJ2.2, U1.3 (+IN)
unnamed: RA1.2, SJ3.1, U1.2 (-IN)
unnamed: C12.2, C22.2, CONN.2, IN.2, OUT.2, RA1.1, RB1.1
unnamed: C11.2, RA2.1 (A), RA2.3 (S), SJ4.1, U1.6 (OUT)
unnamed: R21.1 (E), SJ4.2
unnamed: RA2.2 (E), SJ3.2
unnamed: C21.1, R21.2 (S), R21.3 (A), R22.1 (E)
unnamed: R22.2 (S), R22.3 (A), SJ5.1
unnamed: C22.1, SJ5.2, U2.3 (+IN)
unnamed: C21.2, OUT.1, RB2.1 (A), RB2.3 (S), U2.6 (OUT)
unnamed: RB1.2, SJ6.1, U2.2 (-IN)
unnamed: RB2.2 (E), SJ6.2
unnamed: CONN.1, U1.7 (V+), U2.7 (V+)
unnamed: CONN.3, U1.4 (V-), U2.4 (V-)

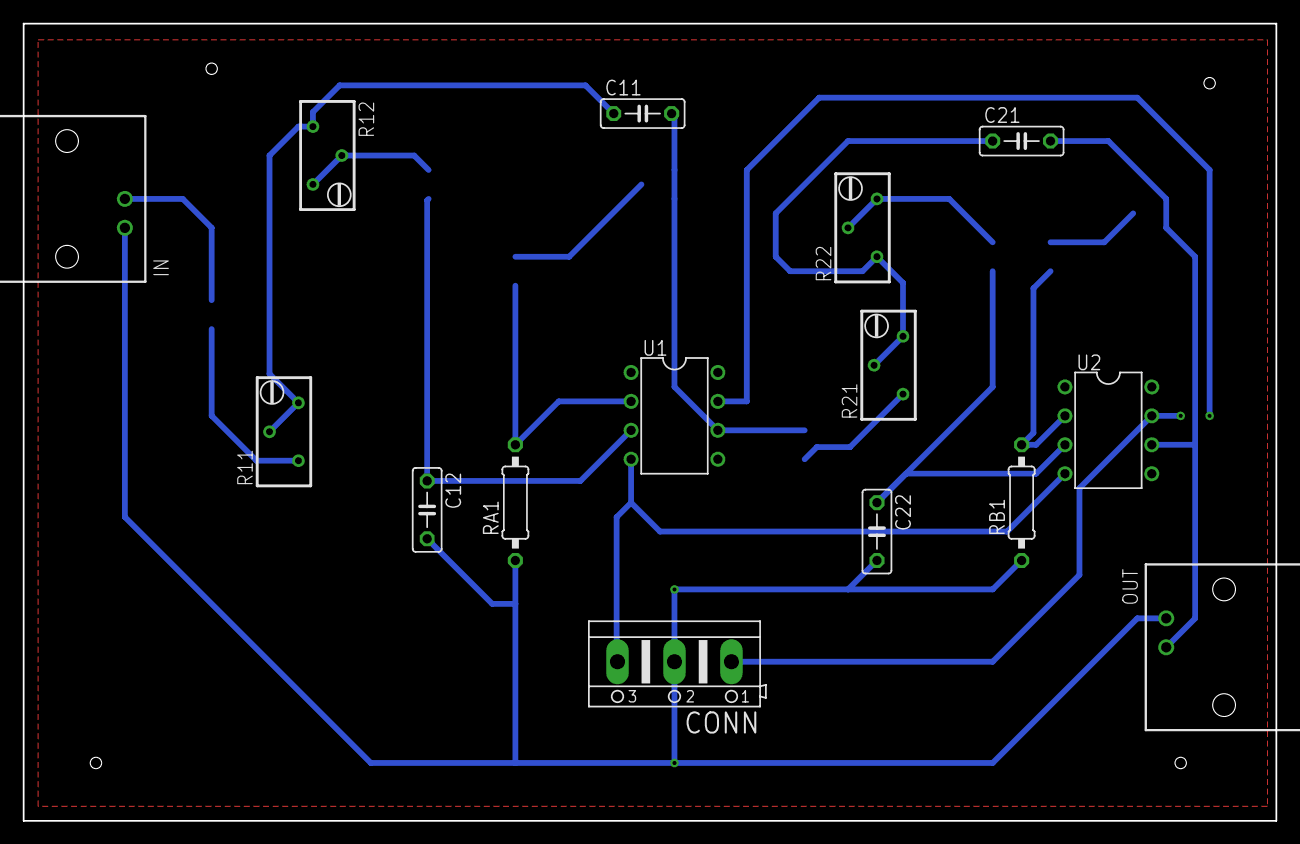
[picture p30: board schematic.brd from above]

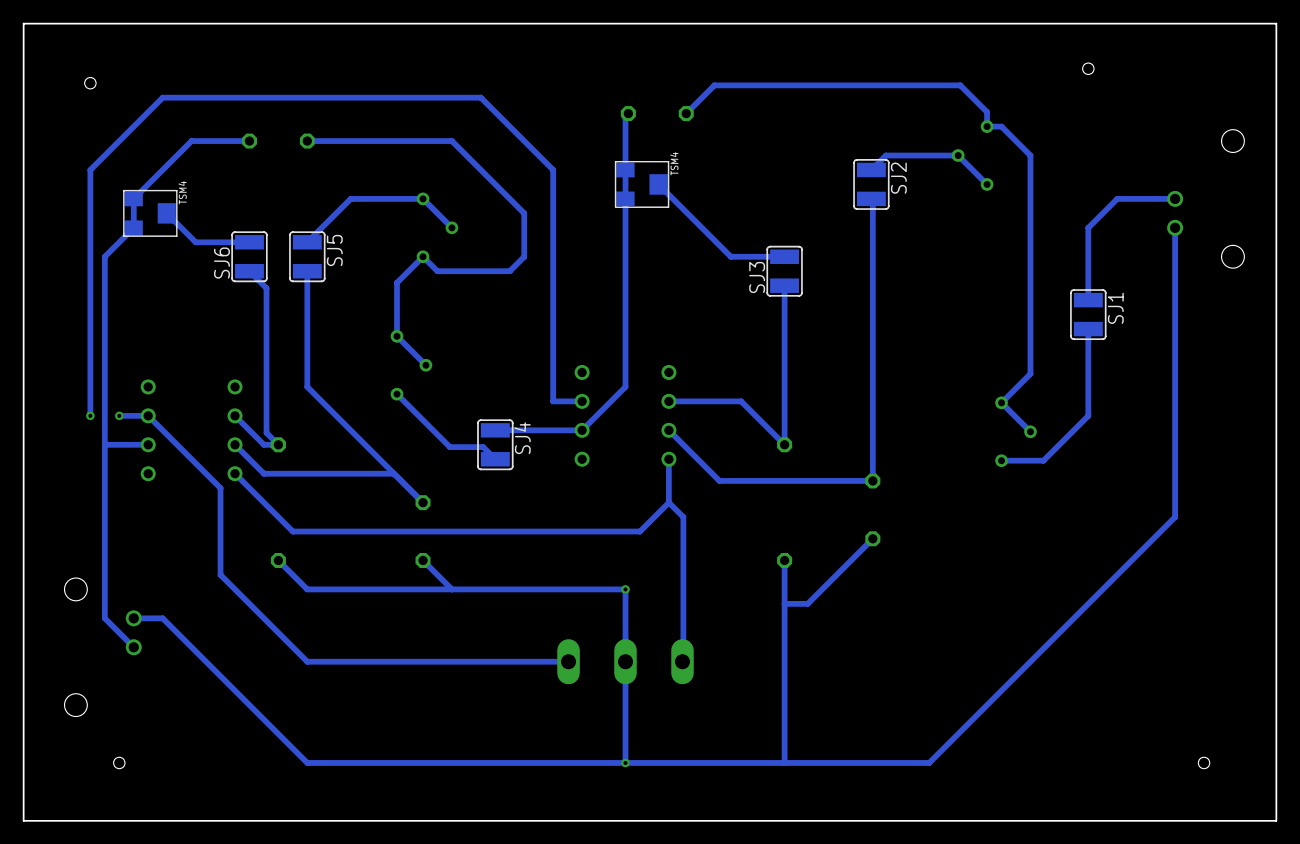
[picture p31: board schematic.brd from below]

Board: 2 copper layers, 110.0 x 70.0 mm, 23 parts (8 on the bottom side), 18 nets.
